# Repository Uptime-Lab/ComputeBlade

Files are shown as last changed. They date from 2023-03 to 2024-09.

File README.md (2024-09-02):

# This page is no longer being updated and the new repo is [uptime-industries/compute-blade](https://github.com/uptime-industries/compute-blade)

# Compute Blade Repository

- [Official website computeblade.com](https://computeblade.com/)

- [Official website uplab.pro](https://uplab.pro/)

- [Instagram](https://www.instagram.com/uptime.lab/)

- [Twitter](https://twitter.com/merocle)

- [Discord community](https://discord.com/servers/uptime-lab-952334175501946902)

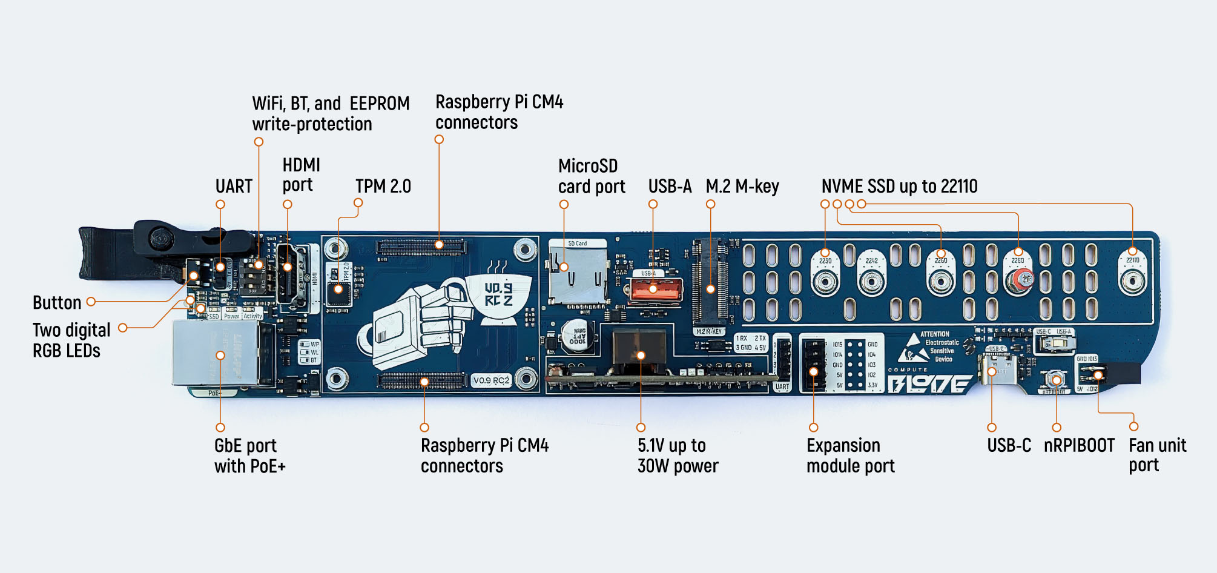
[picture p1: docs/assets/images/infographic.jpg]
Compute Blade


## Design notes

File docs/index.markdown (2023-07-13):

---
title: Compute Blade
layout: page
permalink: "/"
nav_order: 0
---

# Compute Blade

The device is a rack-mountable, PoE-powered carrier board for Raspberry Pi Compute Module 4 and compatible devices with all the necessary interfaces.
With Compute Blade, you can create a high-density, low-power-consuming, plug-and-play blade server for home or data-center use.

infographic

---

40 Raspberry Pi CM4 with NVMe drives in 2 server units:
* 160 ARM cores
* 320 GB Ram
* 20 TB Storage

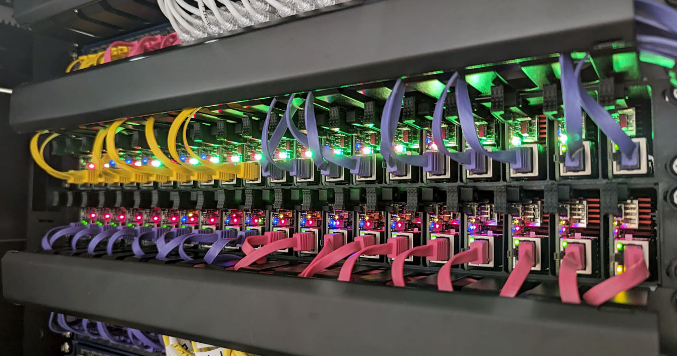
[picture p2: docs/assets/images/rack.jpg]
rack


---

There are 3 options
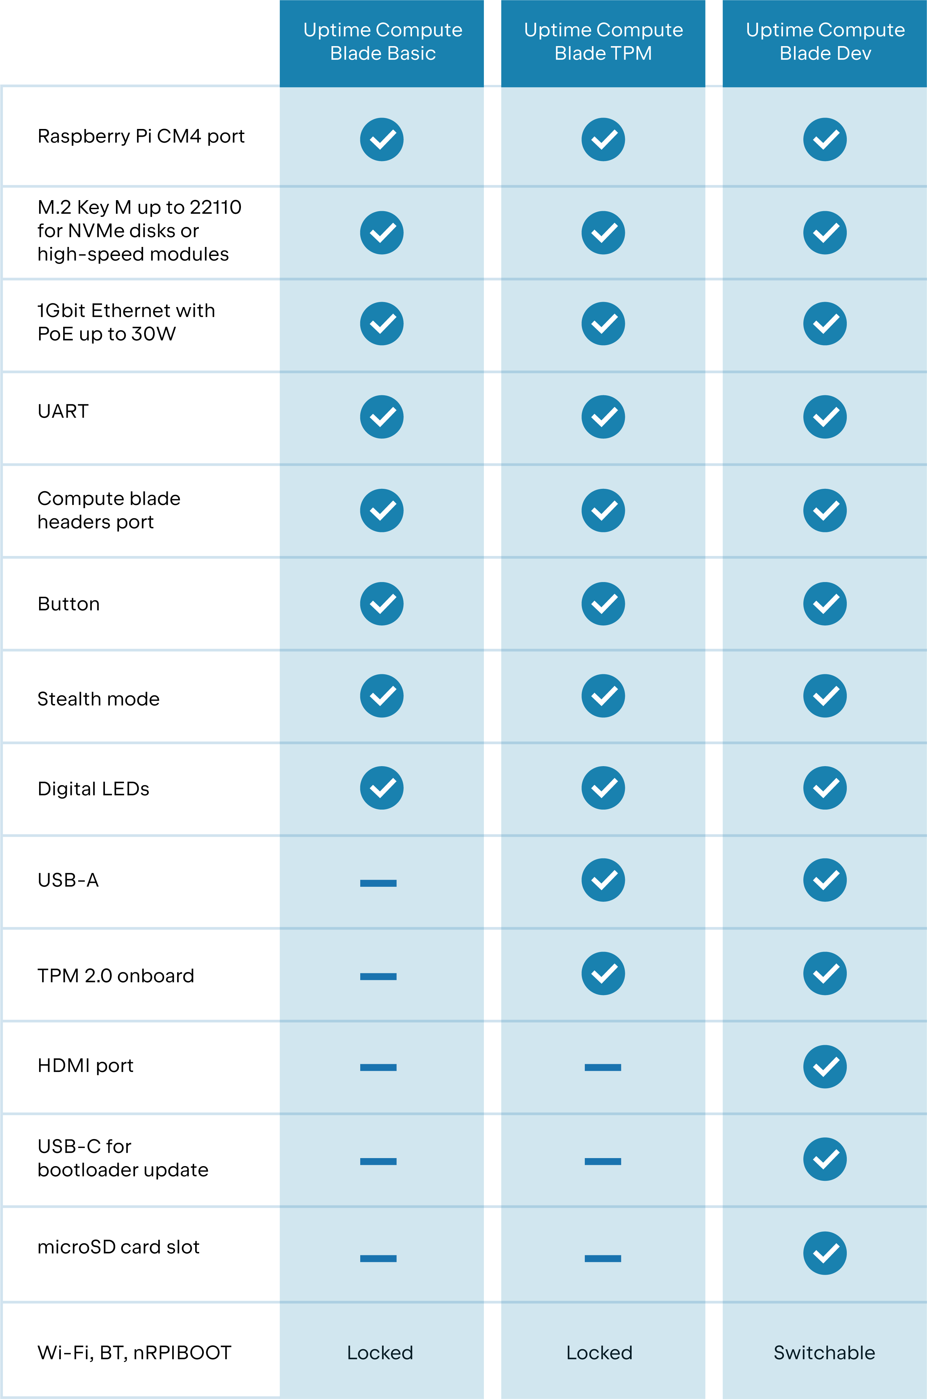
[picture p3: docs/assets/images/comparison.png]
comparison


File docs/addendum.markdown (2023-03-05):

---
title: Addendum
layout: page
permalink: "/addendum/"
nav_order: 7
---
## What do you need to pay attention

---

* The current iteration of the 3D-printed enclosure has a weakness.
I broke one of the Fan Unit latches by inattention, but in general you just need to not over bend or put the chassis standing on it on the table.

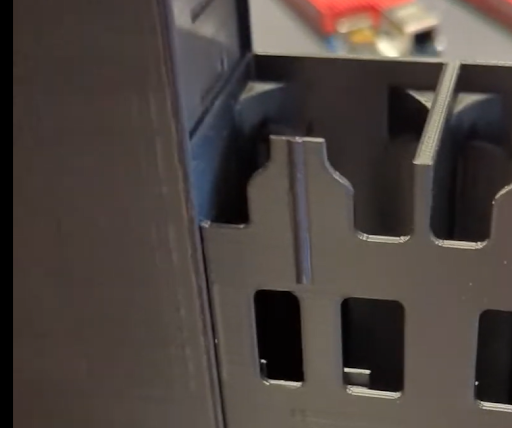
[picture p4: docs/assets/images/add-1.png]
add-1


---

* The second thing to look at is the contact of the Fan Unit assembly.\
  This may not be the most reliable option, because if the connector or pins are slightly bent, they will not fit together or may break. But this is the cheapest and easiest to replace option.
  Just make sure the first time that they are flat and fit together. You can start with a fanless assembly to check the case

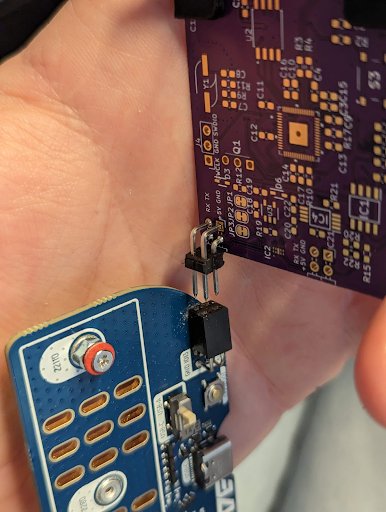
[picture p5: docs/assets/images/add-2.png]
add-2

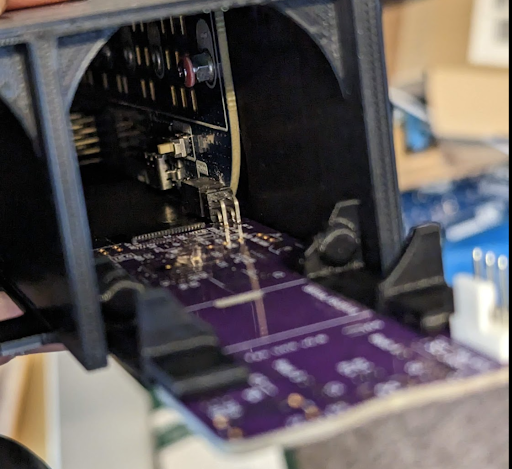
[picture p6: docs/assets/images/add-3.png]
add-3


---

* Processing traces on the edges of the **Compute Blade RC2** PCB\
  Some RC2 blades have irregularities on the borders of the circuit board (the places of separation of the plates), this will be corrected in version 1, but in the meantime need to finalize it with knife or any other tool (incidentally on some blades, I have already done it)

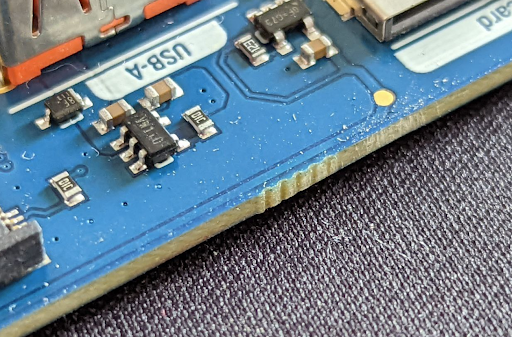
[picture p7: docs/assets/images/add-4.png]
add-4


---

* If you printed the case yourself, note that the blade should go in without difficulty. The model should be printed 1in1 with minimal error.
  When printing with the Cura slicer, I use a “horizontal expansion” setting of “-0.08”
  This is the challenge for the 3D printer. Best of luck!

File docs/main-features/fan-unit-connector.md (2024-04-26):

---
title: Square connector
layout: page
parent: Main Features (Basic Blade)
permalink: "/main-features/fan-unit-connector/"
---
## Square connector at the rear of the Blade

The square connector at the end of the Blade main purpose is to connect a Fan Unit.
The output is 5V and should work with any fan that supports 5V. The speed of the fan can be controlled with PWM.

But it can be used to control any 5v PWM fan. Or as an additional UART port (UART5 on CM4)

{: .warning }
Take care when wiring into this connector!

### UART connection (Smart Fan Unit)

On the Blade
Add to Config.txt

```bash
dtoverlay=uart5
```

> Note:
>
> to find out which port UART5 is on:
> ```bash
> /dev/tty*
> ```
> it would look something like this:
> ```bash
> /dev/ttyAMA1 or /dev/ttyAMA5
> ```

Console (use your UART port):

```bash
sudo apt-get install cu
sudo chmod 666 /dev/ttyAMA5
sudo cu -l /dev/ttyAMA5 -s 115200
```

Fan Unit code:

[https://github.com/merocle/FanUnit](https://github.com/merocle/FanUnit){:target="_blank"}

{: .highlight-title }

> Notes:
>
> to close **cu** session:
> ```bash
> ~.
> ```
> to check if session in the background (in case “**cu: /dev/ttyAMA1: Line in use**” error):
> ```bash
> jobs -l
> ```
> to return to current opened session:
> ```bash
> fg
> ```

### PWM fan (non-smart Fan Unit)

When using a dumb Fan Unit the fan is controlled from the left blade in the pair

Examples:

```bash
wget https://raw.githubusercontent.com/DriftKingTW/Raspberry-Pi-PWM-Fan-Control/master/read_fan_speed.py
```

{: .important }
>You need to change in the script:
>**TACH = 13**

Run the script:

```bash
python read_fan_speed.py
```

Fan Control example:
```bash
wget https://raw.githubusercontent.com/DriftKingTW/Raspberry-Pi-PWM-Fan-Control/master/fan_control.py
python fan_control.py
```

{: .important }
>You need to change in the script:
>**FAN_PIN = 12**

to run the script in the background quickly, run
```bash
nohup python fan_control.py
```
Links:
[https://blog.driftking.tw/](https://blog.driftking.tw/en/2019/11/Using-Raspberry-Pi-to-Control-a-PWM-Fan-and-Monitor-its-Speed/){:target="_blank"}

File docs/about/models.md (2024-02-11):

---
title: 3D Models
layout: page
parent: About
permalink: "/about/models/"
nav_order: 2
redirect_from:
- /models/
---

## Compute Blade
* [Compute Blade v1 DEV (.step)](/assets/files/Compute_Blade_v1_DEV.step){:target="_blank"}
* [Compute Blade v1 TPM (.step)](/assets/files/Compute_Blade_v1_TPM.step){:target="_blank"}
* [Compute Blade v1 Basic (.step)](/assets/files/Compute_Blade_v1_Basic.step){:target="_blank"}

Outdated:
* [Compute Blade RC2 DEV (.step)](/assets/files/Compute_Blade_RC2_DEV.step){:target="_blank"}

## Fan Unit
* [Smart Fan Unit (.step)](/assets/files/Fan_Unit_Smart_V1.1.step){:target="_blank"}
* [Non-smart Fan Unit (.step)](/assets/files/Fan_Unit_Dumb_V1.1.step){:target="_blank"}

## BladeRunner enclosure

* Models for 3D printing are available in [the official repository of the enclosure (link)](https://github.com/Uptime-Lab/BladeRunner){:target="_blank"} 

{: .note-title }
> License
>
> Creative Commons Attribution-ShareAlike (CC BY-SA)

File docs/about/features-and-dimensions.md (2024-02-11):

---
title: Features and Dimensions
layout: page
parent: About
permalink: "/about/features-and-dimensions/"
nav_order: 1
---

<details open markdown="block">
  <summary>
    Table of contents
  </summary>
  {: .text-delta }
- TOC
{:toc}
</details>

## Compute Blade

infographic

### List of Dev revision features

* Raspberry Pi CM4 support
* NVMe SSD up to 22110 (2230, 2242, 2260, 2280 supported)
* Gigabit Ethernet
* Power over Ethernet IEEE 802.3at (PoE+) up to 25.5W (30W peak)
* Raspberry Pi CM4 by PoE 5.1V power supply, which has improved stability under overclocking.
* USB-A for a flash drive for copying data during setup with UART or YubiKey keys during operation.
* MicroSD card port
* UART0 on the front (TX, RX, GND)
* Additional UART0 with 5v in (or out) next to module port
* Two digital RGB LEDs
* Hardware switchable WiFi, BT, and EEPROM write-protection
* Activity, Power, and SSD LEDs
* HDMI port for connecting a monitor (up to 4k60)
* USB-C port and PRIBOOT button to flash the bootloader, access to eMMC/SD card, or tests.
* TPM 2.0 onboard
* PWM fan connector for the custom backplane (Fan Units), supports UART communication.
* Switchable USB input (USB-A or USB-C)
* Programmable button on the front panel
* IEEE 802.3at detection (on Raspberry Pi with GPIO pin and additional LED on the blade).
* Toggleable front LEDs that can be turned off

[Version comparison table](/#comparison)

### Blade Dimensions

* 42,5mm x 255mm x 17.5mm
<br />or
* 1,67" x 10" x 0,69"

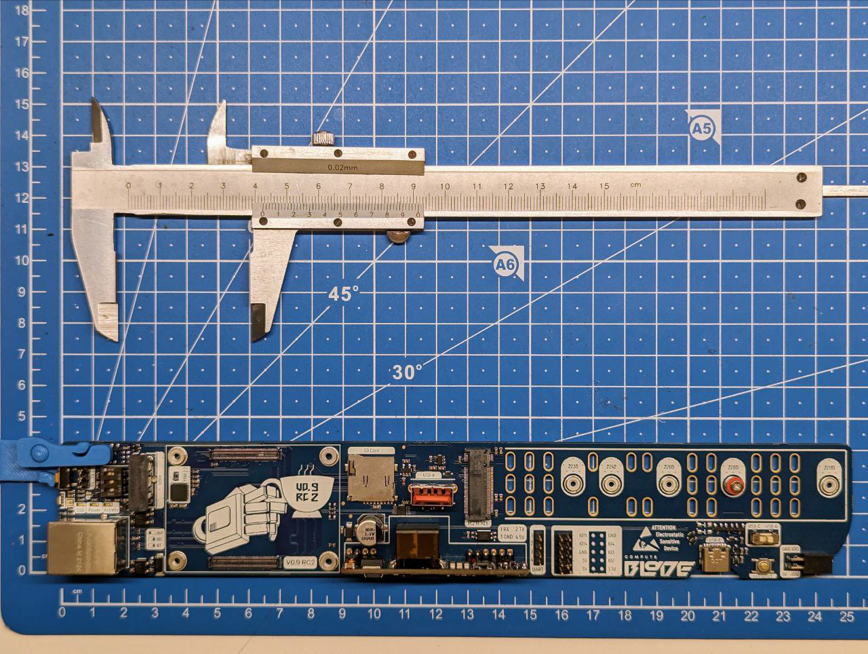
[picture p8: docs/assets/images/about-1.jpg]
Dimensions-1

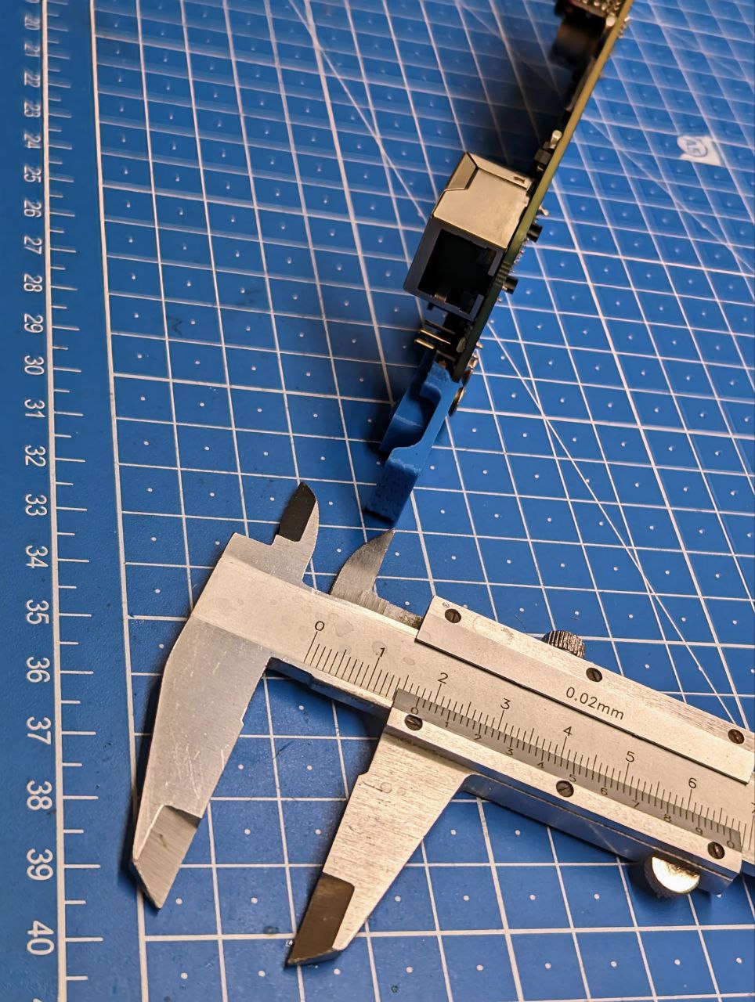
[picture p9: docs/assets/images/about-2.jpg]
Dimensions-2


### Compute Blade Changelog

[From concept to RC2 on uplab.pro](https://uplab.pro/2022/03/compute-blade-changelog/){:target="_blank"}

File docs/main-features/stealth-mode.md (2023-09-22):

---
title: Stealth mode
layout: page
parent: Main Features (Basic Blade)
permalink: "/main-features/stealth-mode/"
---

## Stealth mode

Stealth mode will turn off all but the Digital LEDs at once. It is implemented via a GPIO and a transistor, which means it won't harm the Blade functionality. It is possible to change the brightness using software PWM however in some cases, it may not work perfectly.

Compute Blade RC2 cannot turn off the LEDs on the Ethernet port this way, but they can be turned off in other ways. The Digital LEDs will also not be turned off due to technical limitations, but since they are controlled from the GPIO this should not be a problem.\

Initialization in the terminal:

```bash
echo "21" > /sys/class/gpio/export
echo "out" > /sys/class/gpio/gpio21/direction
```

To turn off the LEDs:

```bash
echo "1" > /sys/class/gpio/gpio21/value
```

To turn on the LEDs:

```bash
echo "0" > /sys/class/gpio/gpio21/value
```

To do this immediately after booting the OS, you can add these commands to /etc/rc.local:

```bash
sudo nano /etc/rc.local
```

```bash
#!/bin/sh -e
#
# rc.local
#

echo "21" > /sys/class/gpio/export
sleep 0.1
echo "out" > /sys/class/gpio/gpio21/direction
echo "1" > /sys/class/gpio/gpio21/value
sleep 0.1

exit 0
```

To switch off LEDs on the Ethernet port add these lines to /boot/config.txt ([Source](https://github.com/raspberrypi/linux/blob/rpi-5.15.y/arch/arm/boot/dts/overlays/README#L172){:target="_blank"})

```bash
#disable ethernet port LEDs
dtparam=eth_led0=14
dtparam=eth_led1=14
```

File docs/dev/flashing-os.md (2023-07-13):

---
title: Flashing OS to eMMC / accessing eMMC
layout: page
parent: Compute Blade Dev
permalink: "/dev/flashing-os/"
---
### Flashing OS to eMMC / accessing eMMC

In short, it's like this:

- On a computer with Linux to which you will connect the Blade

```bash
sudo apt install libusb-1.0-0-dev
git clone --depth=1 https://github.com/raspberrypi/usbboot
cd usbboot
make
cd recovery
sudo ./rpiboot
```

If you have a Mac OS you need [Homebrew](https://brew.sh/){:target="_blank"}

```bash
brew install pkgconfig libusb
```
- Slide the USB switch to USB-C. Press Boot (nRPIBOOT) on the Blade and connect it to your Linux/Mac with USB-C cable

- After that you will be able to mount the Boot partition if present. (it usually happens automatically). Note a stock CM4 has a completely empty eMMC.

You can fix your files/configs or install the OS using the [Raspberry Pi Imager](https://www.raspberrypi.com/software/){:target="_blank"}

For complete instructions, see Jeff Geerling's website: [instructions](https://www.jeffgeerling.com/blog/2020/how-flash-raspberry-pi-os-compute-module-4-emmc-usbboot){:target="_blank"}

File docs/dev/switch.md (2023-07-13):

---
title: Write Protection, Wireless, and Bluetooth Switch
layout: page
parent: Compute Blade Dev
permalink: "/dev/switch/"
---

### Write Protection, Wireless, and Bluetooth Switch

You are able to turn off wireless, Bluetooth and enable the bootloader write protection  
The following pins are:

1 - Write Protection (left - disabled)

2 - Wi-Fi (left - enabled)

3 - Bluetooth (left - enabled)

Switch only when the Blade is off

To activate write protection, you also need to flash the bootloader. Just follow the steps in the official documentation. [Link](https://www.raspberrypi.com/documentation/computers/compute-module.html#cm4bootloader){:target="_blank"}

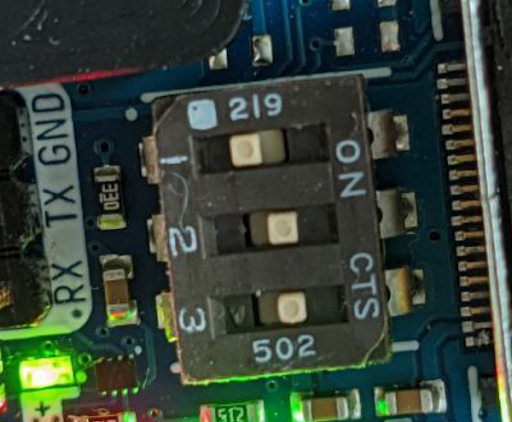
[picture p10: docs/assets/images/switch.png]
switch


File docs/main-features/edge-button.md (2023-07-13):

---
title: Edge button
layout: page
parent: Main Features (Basic Blade)
permalink: "/main-features/edge-button/"
---

## Edge button

{: .note }
The button is connected to GPIO20 in the Raspberry PI compute module and can be customized as you like.
Can be pressed with a left touch of the Blade latch.

Python script example:

```python
import RPi.GPIO as GPIO
import time

GPIO.setmode(GPIO.BCM)
GPIO.setup(20, GPIO.IN, pull_up_down=GPIO.PUD_UP) #Button to GPIO20

try:
    while True:
         button_state = GPIO.input(20)
         if button_state == False:
             print('Button Pressed...')
             time.sleep(0.2)
except:
    GPIO.cleanup()
```

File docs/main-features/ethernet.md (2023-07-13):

---
title: Ethernet with PoE
layout: page
parent: Main Features (Basic Blade)
permalink: "/main-features/ethernet/"
nav_order: 3
---

# Ethernet with PoE

The Compute Blade features a Gigabit Ethernet port that supports IEEE 802.3at (PoE+) and 802.3af (PoE).

## Power Consumption

Power consumption will vary based on load, accessories connected, the power requirements of any devices installed in the M.2 slot, whether or not the CM4 is overlocked, etc.

A compute blade with a CM4 overlocked to 2GHz and a normal NVMe SSD consumes ~7W under load. Normal operation may range from 3W to 17W.

A cluster of 40 blades running CI/CD tasks in a production environment consumes 260-280W, with 20 blades @ 1.8GHz and 20 blades overclocked to 2GHz.

## Cost

The cost to run a blade will depend on the power consumption considerations noted above and your local utility provider's rates. Some providers will vary the cost of electricity over the course of a day (peak vs. non-peak), which can further complicate the equation.

You can use an [energy cost calculator](https://www.rapidtables.com/calc/electric/energy-cost-calculator.html){:target="_blank"} to figure out kWh per day, month, or year, then mulitply that by your local utility provider's rates to determine the total cost to run a blade.

Examples: 

If a blade consumes 10W and runs 24 hours a day, that's 0.24 kWh/d. A fully-populated 19" rack mount shelf with 20 blades would consume 4.8 kWh/d.

* USD: At $0.20 per kWh, a blade would cost $0.048/d, or $0.96/d for a full shelf.
* EUR: At €0.19 per kWh, a blade would cost €0.046/d, or €0.82/d for a full shelf.

## PoE Modules

Different Compute Blade revisions use different PoE modules. See the table below.

| Version | PoE Module | Volts | Watts (Peak) | PoE Support | Classification |
|:---|:---|:---|:---|:---|:---|
| RC2 | [Silvertel Ag5305](https://silvertel.com/ag5300/){:target="_blank"} | 5V | 20W (22W) | IEEE 802.3af, 802.3at | Type 2, Class 4 <sup>1</sup> |
| v1.0 | [Silvertel Ag5405](https://silvertel.com/ag5400/){:target="_blank"} | 5V | 25.5W (30W)  | IEEE 802.3af, 802.3at, 802.3bt | Type 2, Class 4 <sup>2</sup> |

<sup>1</sup> _"The Ag5300 classification is fixed at Class 4, this means that an IEEE802.3at Type 1 or an IEEE802.3af PSE will default to Class 0. However an IEEE802.3at or IEEE802.3bt PSE will recognise the Class 4 as a Type 2 PD." ([source](https://silvertel.com/images/datasheets/Ag5300-datasheet-smallest-30W-Power-Over-Ethernet-Plus-Module-PoEplusPD.pdf))_

<sup>2</sup> _"The Ag5400 is a fixed Type 2 - Class 4 PD requesting 30W of power from a compliant IEEE802.3 Type 2 or greater PSE by displaying the correct class pulses shown in Table 3 below. If the Ag5400 is connected to a Type 1 PSE, the PSE will not recognise the Class 4 request from the Ag5400 and default to a Class 3 power level device and supply 15.4W." ([source](https://silvertel.com/images/datasheets/Ag5400-datasheet-high%20Efficiency-30W-Power-Over-Ethernet-Plus-Module-PoE+PD.pdf))_

## PoE Standards

This is not meant to be an exhaustive reference. For detailed information, see [Power over Ethernet](https://en.wikipedia.org/wiki/Power_over_Ethernet){:target="_blank"}.

| Standard | Common Name  | Type | PD | Max. PSE | 
|:---|:---|:-----|:---|:---|
| [IEEE 802.3af](https://standards.ieee.org/ieee/802.3af/1090/){:target="_blank"} | PoE | 1 | 12.95W | 15.4W |
| [IEEE 802.3at](https://standards.ieee.org/standard/802_3at-2009.html){:target="_blank"} | PoE+ | 2 | 25.5W  | 30.0W |
| [IEEE 802.3bt](https://standards.ieee.org/ieee/802.3bt/6749/){:target="_blank"} | PoE++, 4PPoE | 3 | 51W | 60W |
| [IEEE 802.3bt](https://standards.ieee.org/ieee/802.3bt/6749/){:target="_blank"} | PoE++, 4PPoE | 4 | 71.3W  | 100W |

Use Cat5 cabling or better. Cat3 can be used in certain low-power situations, but most should not find themselves in a situation where Cat3 is needed.

## Switch Recommendation

A switch that supports IEEE 802.3at (PoE+) is recommended. However, IEEE 802.3af (PoE) is sufficient for a blade with a CM4 @ 1.8GHz and a standard NVMe SSD. Future M.2 modules (Coral, RAID, etc.) will require more power; 802.3af may not be adequate.

### Considerations

* PoE standard(s) supported.
* PoE budget.<sup>1</sup>
* Port count.
* Port speed.
* Form factor.

<sup>1</sup> _Note the switch's PSU, switch power consumption, and power available to PoE. Switches are not always capable of providing full power to all available switch ports. For example, a switch with a 500W PSU, with 50W switch power consumption, has a 450W PoE budget. That allows 26.25W per port for a 24-port switch, but only 9.375W for a 48-port switch._ 

### Switches In Use

A list of switches that Compute Blade users have successfully used to connect and power Compute Blades. For reference only.

| Switch | Part No. | Ports | PoE |
|:---|:---|:---|:---|
| [Aruba CX6100 12G](https://www.arubanetworks.com/de/products/switches/access/6100-series/){:target="_blank"} | JL679A | 14x 1GbE RJ45, 2x 1/10GbE SFP+ | 12x PoE+ |
| [Ubiquiti Switch Pro 24 PoE](https://store.ui.com/products/usw-pro-24-poe){:target="_blank"} | USW-PRO-24-POE | 24x 1GbE RJ45, 2x 1/10GbE SFP+ | 16x PoE+, 8x PoE++ |
| [HP 5120-48G-POE+](https://support.hpe.com/hpesc/public/docDisplay?docId=emr_na-c00778577){:target="_blank"} | JG237A | 48x 1GbE RJ45, 4x SFP, 2x Expansion | 48x PoE+ |
| [Juniper EX3300-24P](https://www.juniper.net/documentation/en_US/release-independent/junos/information-products/pathway-pages/ex-series/ex3300/ex3300.pdf){:target="_blank"} | EX3300-24P | 24x 1GbE RJ45, 4x 1/10GbE SFP+ | 24x PoE+ |
| [Juniper EX3300-48P](https://www.juniper.net/documentation/en_US/release-independent/junos/information-products/pathway-pages/ex-series/ex3300/ex3300.pdf){:target="_blank"} | EX3300-48P | 48x 1GbE RJ45, 4x 1/10GbE SFP+ | 48x PoE+ |
| [Zyxel GS1200-5HP v2](https://www.zyxel.com/us/en-us/products/switch/5-port-8-port-web-managed-poe-gigabit-switch-gs1200-poe-series){:target="_blank"} | GS1200-5HPV2-EU0101F | 5x 1GbE RJ45 | 4x PoE+ |

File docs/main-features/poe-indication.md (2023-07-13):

---
title: PoE+ indication
layout: page
parent: Main Features (Basic Blade)
permalink: "/main-features/poe-indication/"
nav_order: 4
---

# PoE+ Indicator

The PoE+ Indicator can be used to monitor power supply failures or limit RaspberryPi overclocking, when power is provided via 802.3af only.
There is an LED on the Blade with a `+` label indicating the PoE+ power state.
Alongside, GPIO23 can be used to identify the power state.

|--------------------|--------------------------------------------|----------|----------------|
| LED Color          | Description                                | GPIO 23  | Power          |
|--------------------|--------------------------------------------|----------|----------------|
| Red                | 5 Volt present (PoE or USB-C or 5v direct) | **HIGH** | 12W            |
| Orange (Red+Green) | PoE+ (802.3at) present                     | **LOW**  | 25W (RC2: 22W) |
|--------------------|--------------------------------------------|----------|----------------|

<table>
  <tr>
    <td>
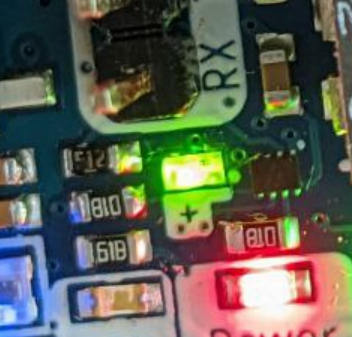
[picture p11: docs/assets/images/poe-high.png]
        
        <h3>PoE or USB-C or 5v direct </h3>
    </td>
    <td>
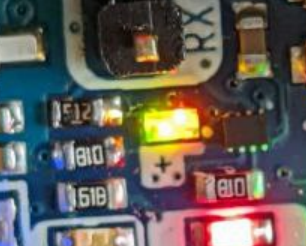
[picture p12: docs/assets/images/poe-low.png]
        
        <h3>PoE+ Detected </h3>
    </td>
   </tr>
</table>

## Accessing the PoE+ status in software

The GPIO23 indicates the PoE+ state, this Python script can e.g. used to detect the status.

```python
import RPi.GPIO as GPIO
import time

POE_INDICATOR_GPIO = 23

GPIO.setmode(GPIO.BCM)
GPIO.setup(POE_INDICATOR_GPIO, GPIO.IN, pull_up_down=GPIO.PUD_UP) # PoE indicator

try:
     button_state = GPIO.input(POE_INDICATOR_GPIO)
     if button_state == False:
        print("Powersource: 802.3at")
    else:
        print("Powersource: 802.3af or USB-C")
except:
    GPIO.cleanup()
```

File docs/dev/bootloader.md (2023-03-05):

---
title: Flashing the bootloader
layout: page
parent: Compute Blade Dev
permalink: "/dev/bootloader/"
---
### Flashing the bootloader

To flash the bootloader, you need to turn on the Blade with the nRPIBOOT button pressed (a second after turning the Blade on, you can already release it).
You can turn it on from USB-C or PoE; it doesn't matter. To flash, you need to plug in a USB-C and switch the switch to USB-C (the switch can be switched during operation).

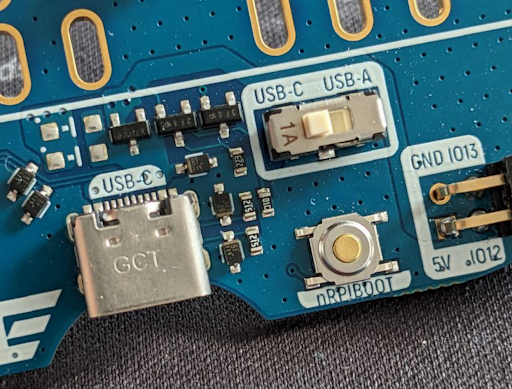
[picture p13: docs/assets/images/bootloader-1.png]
bootloader-1


On a computer with Linux to which you will connect the Blade:

```bash
sudo apt install libusb-1.0-0-dev
git clone --depth=1 https://github.com/raspberrypi/usbboot
cd usbboot
make
cd recovery
nano boot.conf
```

change the line

```
BOOT_ORDER=0xf16
```

That means:

Try NVMe first, followed by SD then repeat.

You can find more about boot order by following this [link](https://www.raspberrypi.com/documentation/computers/raspberry-pi.html#BOOT_ORDER){:target="_blank"}.

Optionally, I also recommend correcting 0 to 1 on this line to enable UART on boot

```
BOOT_UART=1
```

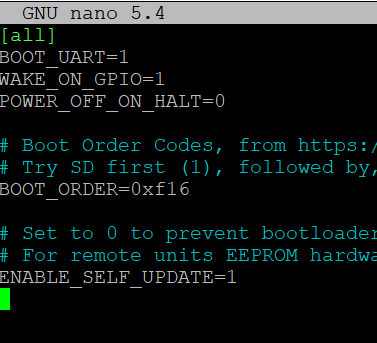
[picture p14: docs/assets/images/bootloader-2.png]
bootloader-2


To update to the latest bootloader version use [repo](https://github.com/raspberrypi/rpi-eeprom/tree/master/firmware){:target="_blank"} and the right link:

```bash
rm -f pieeprom.original.bin
curl -L -o pieeprom.original.bin  https://github.com/raspberrypi/rpi-eeprom/raw/master/firmware/stable/pieeprom-2022-12-07.bin
```

```bash
./update-pieeprom.sh
cd ../
sudo ./rpiboot -d recovery
```

If UART is connected, you will see the firmware status. If the HDMI port is connected, the screen will turn green.

on UART (you should use BOOT_UART=1 in boot.conf):

bootloader-3

Check the bootloader version:

```bash
vcgencmd bootloader_version
```

Also, on the UART when booting:

bootloader-4

If the screen is red and in the UART during flashing:

```
Bad signature pieeprom.bin
FATAL error-code 24
```

You are probably using the wrong pieeprom.original.bin image. The right one should be 512k in size.

pieeprom.original.bin

In my case, the problem was due to an incorrect link (**blob** in the path):

~~https://github.com/raspberrypi/rpi-eeprom/blob/master/firmware/stable/pieeprom-2022-09-02.bin~~The correct one:

https://github.com/raspberrypi/rpi-eeprom/raw/master/firmware/stable/pieeprom-2022-09-02.bin

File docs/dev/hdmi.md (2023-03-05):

---
title: HDMI
layout: page
parent: Compute Blade Dev
permalink: "/dev/hdmi/"
---

### HDMI

The HDMI port is mostly designed for debugging. The port is fragile, so be careful. If possible, use a small flexible cable. If it does break off take care to ensure the board isn’t shorted.

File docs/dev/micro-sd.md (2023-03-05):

---
title: MicroSD card slot
layout: page
parent: Compute Blade Dev
permalink: "/dev/micro-sd/"
---

### MicroSD card slot

The MicroSD card slot only works with the Raspberry Pi CM4 lite

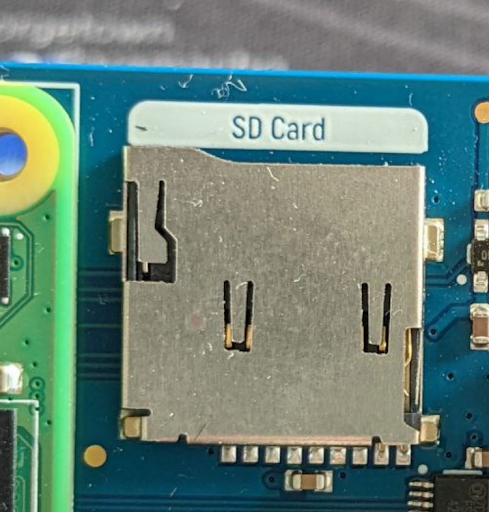
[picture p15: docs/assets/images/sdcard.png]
sdcard


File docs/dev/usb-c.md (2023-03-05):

---
title: USB-C
layout: page
parent: Compute Blade Dev
permalink: "/dev/usb-c/"
---

### USB-C

The compute module can only operate one USB port at a time. 
There is a switch to enable which port you would like to utilize.

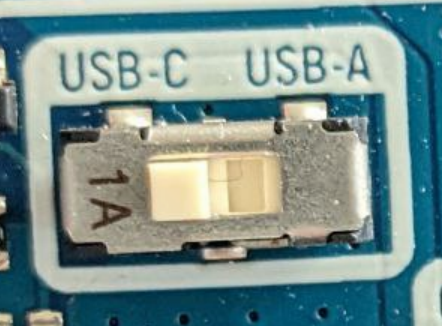
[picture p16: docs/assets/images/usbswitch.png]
usbswitch


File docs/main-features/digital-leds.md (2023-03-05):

---
title: Digital LEDs
layout: page
parent: Main Features (Basic Blade)
permalink: "/main-features/digital-leds/"
---
## Digital LEDs

The blade has two digital LEDs mounted in series. A square yellow LED is located on the top of the board, and a green LED is located on edge.

{: .note }
Both LEDS are connected in series to GPIO18 on the compute module.

Preparation:

You'll need to install the Adafruit_Blinka library that provides CircuitPython support in Python:

[https://learn.adafruit.com/circuitpython-on-raspberrypi-linux/installing-circuitpython-on-raspberry-pi](https://learn.adafruit.com/circuitpython-on-raspberrypi-linux/installing-circuitpython-on-raspberry-pi){:target="_blank"}

And then NeoPixel Library:

[https://learn.adafruit.com/neopixels-on-raspberry-pi/python-usage](https://learn.adafruit.com/neopixels-on-raspberry-pi/python-usage){:target="_blank"}

{: .note }

Newer CM4 Revisions aren’t included in rpi-ws281x yet (e.g. Compute Module 4 Rev 1.1). If you get **“RuntimeError: ws2811_init failed with code -3 (Hardware revision is not supported)”**, you need to follow [these steps](https://github.com/rpi-ws281x/rpi-ws281x-python/issues/56#issuecomment-753320723){:target="_blank"}

Here is an example Python script that will show you the CPU temperature on the square LED and the CPU load on edge LED. And use the button for blade identification. And [demo](https://twitter.com/Merocle/status/1569364547143897088?s=20&t=DmDRg0925cGQrCRTUISCFg){:target="_blank"}

```python
from time import sleep
import board
import neopixel
import psutil
import RPi.GPIO as GPIO

g,r,b = 0,0,0
mintemp = 40 #Temperature Boundaries. Closer to this is green
maxtemp = 70 #Temperature Boundaries. Closer to this is red
LEDbrightness = 0.2 #Yes, you can change the brightness here
Button = 20
flag = 0

GPIO.setwarnings(False)
GPIO.setmode(GPIO.BCM)
GPIO.setup(Button,GPIO.IN,pull_up_down=GPIO.PUD_UP)
pixels = neopixel.NeoPixel(
    board.D18, 2, brightness=LEDbrightness, auto_write=False, pixel_order=neopixel.GRB
)

def show(percent, pixel):
    a = int(round((510 / 100) * percent))
    if a > 255:
        r = 255
        g = 510 - a
    else:
        r = a
        g = 255
    pixels[pixel] = (g, r, b)
    pixels.show()
#    return print('showed', a, 'on', pixel)

while True:
    temp = int(round(psutil.sensors_temperatures()["cpu_thermal"][0].current))
#    print('temp = ', temp)
    button_state = GPIO.input(Button)
    if mintemp <= temp <= maxtemp:
        temp = temp - mintemp
        mtemp = maxtemp - mintemp
        c = int(round((temp / mtemp) * 100))
        show(c, 0)
    elif temp < mintemp:
        pixels[0] = (255, 0, 0)
    else:
        pixels[0] = (0, 255, 0)

    sleep(0.1)

    load = psutil.cpu_percent()
 #   print('load = ', load)
    show(load, 1)
    sleep(0.1)

    if button_state == 0:
        sleep(0.5)
        if flag == 0:
            flag = 1
        else:
            flag = 0
    if flag == 1:
        print('Blade ID is active')
        pixels[1] = (0, 0, 255)

    else:
        print('Blade ID isn\'t active')
```

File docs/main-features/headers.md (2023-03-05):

---
title: Compute blade headers
layout: page
parent: Main Features (Basic Blade)
permalink: "/main-features/headers/"
nav_order: 6
has_children: true
---

You can use Real-Time Clocks (RTCs) for the Raspberry Pi and other compatible modules.
<br />
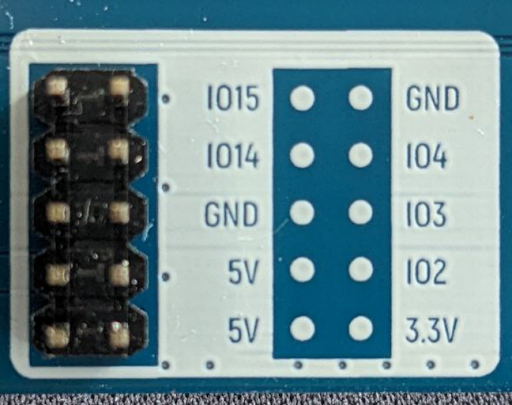
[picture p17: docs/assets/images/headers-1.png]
headers-1


This is the top part of the standard GPIO connector of the Raspberry Pi (upside down)

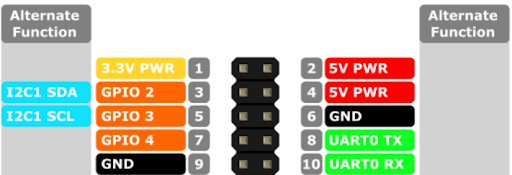
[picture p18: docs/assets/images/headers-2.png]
headers-2
<br />
 [picture source](https://learn.microsoft.com/de-de/windows/iot-core/learn-about-hardware/pinmappings/pinmappingsrpi){:target="_blank"}
{: .fs-1 }
<br />

{: .note }
This section of the documentation will be updated

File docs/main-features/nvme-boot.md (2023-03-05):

---
title: NVMe Boot
layout: page
parent: Main Features (Basic Blade)
permalink: "/main-features/nvme-boot/"
nav_order: 1
---

Works out of the box on the latest (after July 2021) Raspberry Pi CM4. 
If you're not using the latest Raspberry Pi CM4, you’ll need to [update the bootloader](/dev/bootloader/) specifying the correct boot order.

Use standoff for the NVMe drive, 2mm (2.5mm works fine) high.\
**M.2 key M** connection port. Sizes: 
* 2230
* 2242
* 2260
* 2280
* 22110

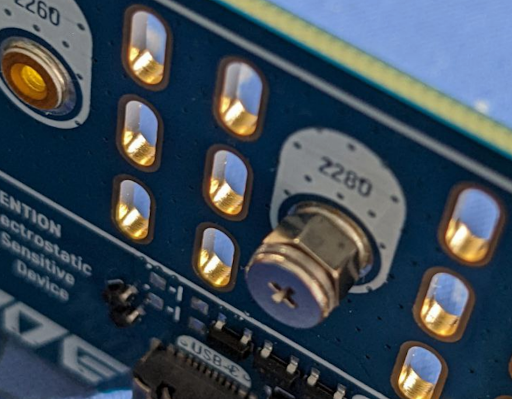
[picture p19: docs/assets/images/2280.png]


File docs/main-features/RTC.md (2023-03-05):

---
title: Real-Time Clocks
layout: page
parent: Compute blade headers
grand_parent: Main Features (Basic Blade)
permalink: "/main-features/headers/rtc/"
nav_order: 1
---
### Using and configuring the RTC module
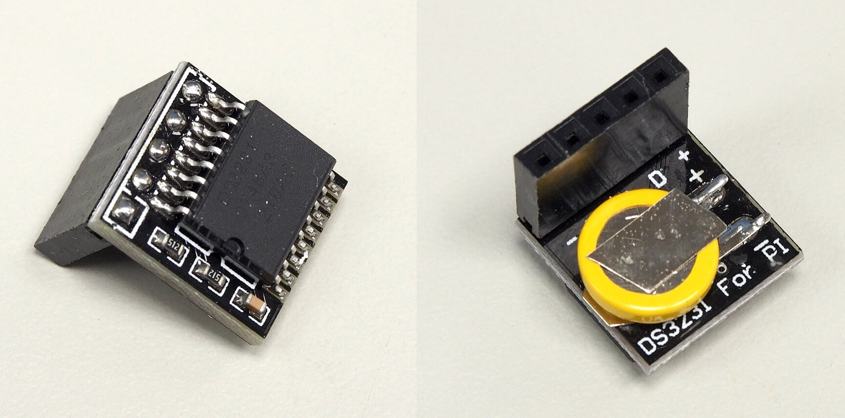
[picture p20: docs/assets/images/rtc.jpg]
rtc


In config:
```bash
dtoverlay=i2c-rtc,ds3231
dtparam=i2c_arm=on
```

Reboot and then check it in the terminal that the i2c device is available:

```bash
sudo i2cdetect -l|sort
sudo i2cdetect -y 1 
```

Next is the setup:

```bash
sudo apt-get -y remove fake-hwclock
sudo update-rc.d -f fake-hwclock remove
sudo systemctl disable fake-hwclock
```

Edit the file **hwclock-set**:

```bash
sudo nano /lib/udev/hwclock-set
```
Complete file:
```bash
#!/bin/sh
# Reset the System Clock to UTC if the hardware clock from which it
# was copied by the kernel was in localtime.

dev=$1

#if [ -e /run/systemd/system ] ; then
#    exit 0
#fi

if [ -e /run/udev/hwclock-set ]; then
    exit 0
fi

if [ -f /etc/default/rcS ] ; then
    . /etc/default/rcS
fi

# These defaults are user-overridable in /etc/default/hwclock
BADYEAR=no
HWCLOCKACCESS=yes
HWCLOCKPARS=
HCTOSYS_DEVICE=rtc0
if [ -f /etc/default/hwclock ] ; then
    . /etc/default/hwclock
fi

if [ yes = "$BADYEAR" ] ; then
#    /sbin/hwclock --rtc=$dev --systz --badyear
    /sbin/hwclock --rtc=$dev --hctosys --badyear
else
#    /sbin/hwclock --rtc=$dev --systz
    /sbin/hwclock --rtc=$dev --hctosys
fi

# Note 'touch' may not be available in initramfs
> /run/udev/hwclock-set
```

Reboot and check in terminal:

```bash
timedatectl status
```

Read:

```bash
sudo hwclock -r
```

Write:

```bash
sudo hwclock -w
```

Additional info

```bash
sudo hwclock --verbose
```

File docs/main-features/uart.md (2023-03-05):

---
title: UART
layout: page
parent: Main Features (Basic Blade)
permalink: "/main-features/uart/"
nav_order: 2
---
This is the same UART0 port, but with the big one, you can use 5V in/out (in "in" mode ONLY if the Blade has no other power source)

{: .note }
> Connect "correctly":
> * RX -> TX
> * TX -> RX
> * GND -> GND

in config:
```bash
enable_uart=1
```

You can [change the bootloader setting](/dev/bootloader/) to enable UART from the boot.
Add this line to boot.conf and flash the bootloader:
```bash
BOOT_UART=1
```
Follow [this link](https://www.raspberrypi.com/documentation/computers/raspberry-pi.html#BOOT_UART){:target="_blank"} to the Raspberry Pi Documentation BOOT_UART value

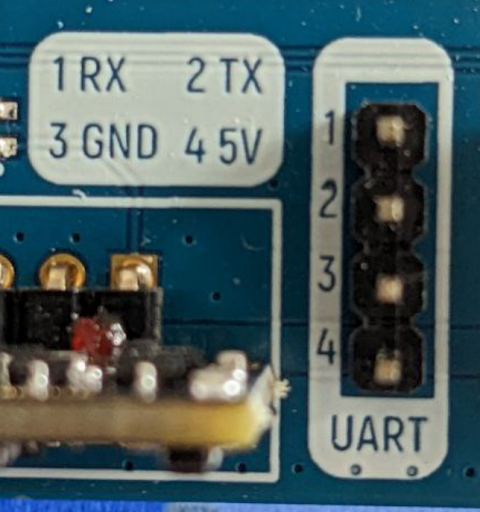
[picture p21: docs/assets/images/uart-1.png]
uart-1

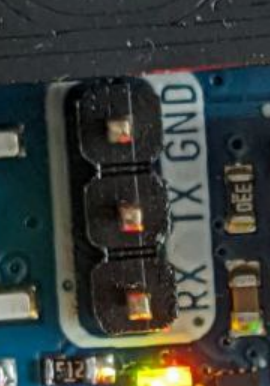
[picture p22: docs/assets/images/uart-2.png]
uart-2


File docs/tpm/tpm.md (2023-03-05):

---
title: TPM and Secure Boot
layout: page
parent: Compute Blade TPM and Dev
permalink: "/tpm-and-dev/tpm/"
---
## TPM

In config:

```bash
dtparam=spi=on dtoverlay=tpm-slb9670
```

To check

In terminal:

```bash
mkdir infineon-tpm 
git clone https://github.com/infineon/eltt2
cd eltt2
make
sudo ./eltt2 -g
cd ..
```

For more information, please see these links:
[https://www.infineon.com/dgdl/Infineon-OPTIGA-TPM-Quick-Start-Guide-AdditionalProductInformation-v03_00-EN.pdf](https://www.infineon.com/dgdl/Infineon-OPTIGA-TPM-Quick-Start-Guide-AdditionalProductInformation-v03_00-EN.pdf){:target="_blank"}

[https://aws.amazon.com/ru/blogs/iot/using-a-trusted-platform-module-for-endpoint-device-security-in-aws-iot-greengrass/](https://aws.amazon.com/ru/blogs/iot/using-a-trusted-platform-module-for-endpoint-device-security-in-aws-iot-greengrass/){:target="_blank"}

## Secure Boot

At the end of 2022, Secure Boot support appeared.

Secure boot is a mechanism for verifying the integrity of the kernel+initramfs and other files required during boot by storing them in a signed ramdisk image. These files include the GPU firmware (start.elf etc), kernel, initrd, Device Tree and overlays.

Secure Boot Quickstart:

[https://github.com/raspberrypi/...](https://github.com/raspberrypi/usbboot/blob/master/secure-boot-example/README.md){:target="_blank"}

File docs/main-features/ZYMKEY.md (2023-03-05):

---
title: ZYMKEY 4i
layout: page
parent: Compute blade headers
grand_parent: Main Features (Basic Blade)
permalink: "/main-features/headers/zymkey/"
nav_order: 2
---
### ZYMKEY 4i

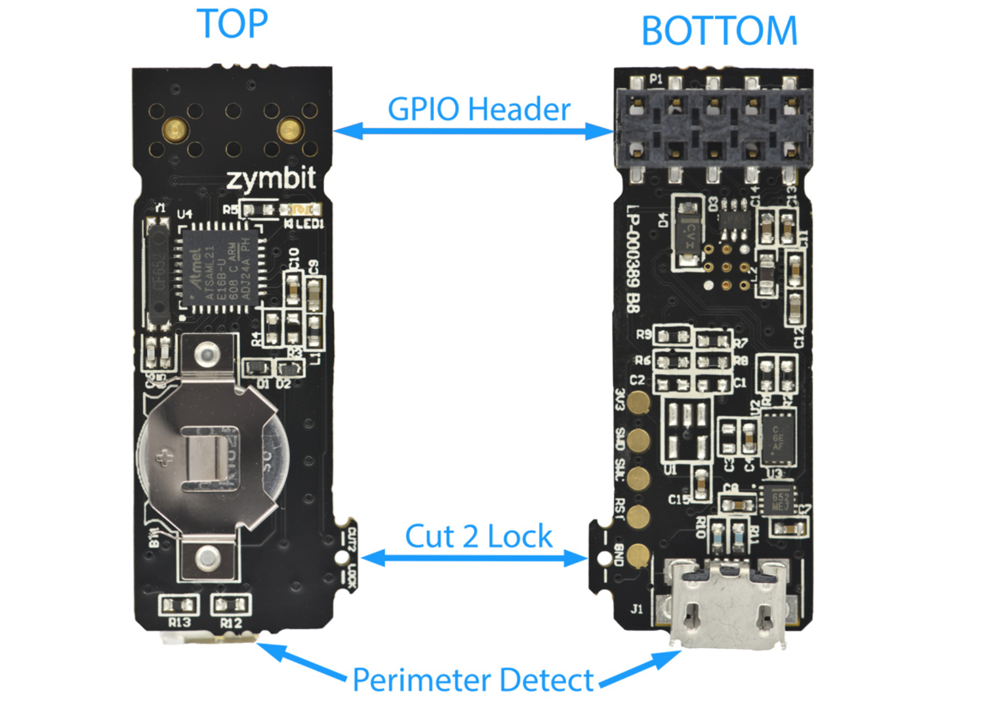
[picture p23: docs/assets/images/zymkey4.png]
zymkey4

#### [quickstart guide 🔗](https://docs.zymbit.com/getting-started/zymkey4/quickstart/){:target="_blank"}

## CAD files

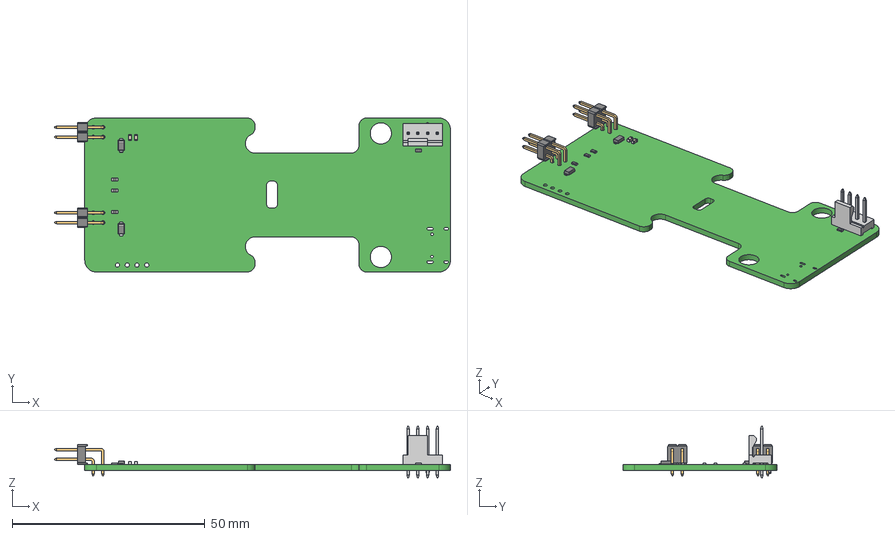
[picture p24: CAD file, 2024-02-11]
docs/assets/files/Fan_Unit_Dumb_V1.1.step
102.9 x 40.0 x 13.5 mm
res0603 x 4
6130xx21021_PIN x 4
6130xx21021_PIN_G x 4
User Library-SOD-123FL x 2
User Library-CAP_0603_CAP_0603_Lead_1 x 4
User Library-CAP_0603_CAP_0603_Body_1 x 2

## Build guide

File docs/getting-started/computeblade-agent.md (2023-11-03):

---
title: Setting up the ComputeBlade Agent
layout: page
parent: Getting Started
permalink: "/getting-started/computeblade-agent/"
nav_order: 3
---

The [computeblade-agent](https://github.com/Uptime-Lab/computeblade-agent) is an OS agent interfacing with the ComputeBlade hardware.
It controls fan speed, LEDs and handles common events e.g. to identify/find an individual blade in a server rack.
In addition, it exposes hardware- and agent-related metrics on a Prometheus endpoint.

Detailed configuration options and install instructions are documented on the [GitHub Repo](https://github.com/uptime-lab/computeblade-agent). The **TL;DR** in case you just want to install it:
```bash
curl -L -o /tmp/computeblade-agent-installer.sh https://raw.githubusercontent.com/Uptime-Lab/computeblade-agent/main/hack/autoinstall.sh
chmod +x /tmp/computeblade-agent-installer.sh
/tmp/computeblade-agent-installer.sh
```

Here's a small demo video of the identify operation in-action:
Video (https://youtu.be/ik-7X-YZQ9c)

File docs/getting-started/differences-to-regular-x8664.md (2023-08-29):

---
title: RasberryPi compared to regular x86/64 processors
layout: page
parent: Getting Started
permalink: "/getting-started/rpi-compare-x86/"
nav_order: 2
---

This page compares the RaspberryPi platform against regular commodity hardware (x86/64) and things to watch out for.

# x86/amd64 vs ARM64 architecture

The x86 platform, prevalent in regular computers, offers robust performance, broad software compatibility, and a variety of operating system options. It's well-suited for resource-intensive tasks, software development, and versatile computing needs.

In contrast, the ARM64 platform, exemplified by the RaspberryPi, prioritizes power efficiency, compact form factors, and IoT/embedded applications. With a strong Linux ecosystem, ARM64 devices are tailored for specialized projects, educational exploration, and scenarios where low power consumption and small size are paramount.

Ultimately, the choice between x86 and ARM64 depends on the intended purpose, ranging from high-performance computing to energy-efficient projects and hands-on learning experiences.

The software support for ARM64 is gaining significant improvements since 2022, when Apple switched its notebooks to the same architecture.

While not being as powerful compared to a regular Server, the RaspberryPi Compute Module can run demanding software while keeping power consumption low.
This allows high-density dedicated servers (aka the ComputeBlade) running without having a full datacenter in the basement.

# Compatibility
Given the difference in architecture, the RaspberryPi does not support all software out of the box.
However, no ARM64 support is the exception rather than the rule.

# Boot Process Differences: x86 vs. ARM64 (RaspberryPi)

The boot process of x86 and ARM64 platforms, such as the RaspberryPi, diverges due to architectural distinctions and hardware considerations:

### x86 Boot Process:
1. **Firmware:* x86 computers typically use BIOS (Basic Input/Output System) or UEFI (Unified Extensible Firmware Interface) as their firmware. These firmware interfaces initialize hardware components, locate the boot device, and load the bootloader.

2. **Bootloader:** The bootloader, often GRUB or similar software, loads the operating system kernel from the boot device (usually a hard drive or SSD). It also handles the selection of the desired operating system if multiple options are available.

3. **Kernel Initiation:** Once the bootloader hands off control to the operating system kernel, the kernel initializes the hardware, mounts the root filesystem, and starts the user-space processes.

### ARM64 Boot Process (RaspberryPi):
> More details can be found in the [official documentation](https://www.raspberrypi.com/documentation/computers/compute-module.html).

1. **Firmware:** The RaspberryPi uses a specialized bootloader known as the RaspberryPi Bootloader (often referred to as `bootcode.bin`). This firmware, stored in the boot partition of the SD card, initializes the ARM processor cores, memory, and peripherals.

2. **GPU Firmware:** The GPU firmware (included in `bootcode.bin`) initializes the VideoCore GPU and loads the initial kernel image (`kernel.img`) into memory.

3. **ARM64 Kernel:** The loaded kernel initializes the ARM64 processor cores, configures memory, and starts essential kernel processes. The kernel is typically paired with a device tree blob (`*.dtb` file) that describes the hardware configuration.

4. **Kernel Initiation:** Once the ARM64 kernel is operational, it mounts the root filesystem, initializes drivers, and launches user-space processes.

The ARM64 boot process for the RaspberryPi involves a multi-stage process that leverages the GPU firmware and a specialized bootloader, ultimately loading the ARM64 kernel and initializing the system. In contrast, x86 systems use more standardized firmware interfaces and bootloaders, similar to those found in traditional desktop and laptop computers.

These differences reflect the distinct hardware architectures of x86 and ARM64 platforms, influencing how the system initializes and loads the operating system.

## U-Boot, UEFI and more

Once working with more specific operating systems for the RaspberryPi, projects like [u-boot](http://u-boot.readthedocs.io) or [pftf/RPI4](https://github.com/pftf/RPi4) (UEFI for RaspberryPi 4) appear.

Without going into too much detail here, both are more standardised bootloaders with u-boot being very specific for embedded devices and UEFI being a more mainstream solution.
In the context of the RaspberryPi, both are loaded **instead** of the Linux kernel directly.

Once executed, they take care of further initialising the hardware and loading the actual Linux kernel.
E.g. [Talos Linux](http://talos.dev), a tailored distribution of Kubernetes, uses u-boot for all of its supported embedded boards where it acts as a standardisation layer of the boot process.

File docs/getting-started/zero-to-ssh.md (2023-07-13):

---
title: From Zero to SSH
layout: page
parent: Getting Started
permalink: "/getting-started/zero-to-ssh/"
nav_order: 1
---

This getting started guide is intended to provide a generic starting ground, covering all steps required to get an SSH session to your blade.
While you can use the Blade with an SD-Card or the embedded eMMC as boot drive, this guide focuses on using the NVMe drive.

# 0. Checklist

- [ ] A PoE capable switch (802.3af or 802.3at). [Here](/main-features/ethernet/) is a list of known-working models.
- [ ] A LAN cable
- [ ] Any version of the ComputeBlade (check [here](/) for details )
- [ ] A [Raspberry Pi Compute Module 4 (CM4)](https://www.raspberrypi.com/products/compute-module-4/?variant=raspberry-pi-cm4001000). In case you plan running [Kubernetes](http://kubernetes.io) on it, make sure to get at least 4GB of memory.
- [ ] An NVMe SSD. Any capacity works, ~500GB seems to be the sweet-spot as of July 2023. A list of already verified drives is located [here](/supported-ssds/).
- [ ] (recommended) A heatsink for the CM4
- [ ] An NVMe to USB adapter. The cheapest option supporting PCIe-based NVMe drives should work.

# 1. Setting up the hardware

1. Install the CM4 on the ComputeBlade
Make sure to line up the CM4 in the correct orientation. It fits only one way! Apply gentle downward facing pressure to the CM4 - you will hear the connectors snapping in.

2. Install the heatsink on the CM4.
Make sure there is sufficient heihgt clearance, when not using the heatsink offered by the ComputeBlade project

3. Plug everything into your PoE switch
This is just a sanity check to see if everything was installed properly!
The LEDs should power on. If they do not, something is not installed correctly or your switch might be incompatible.

4. Unplug the ComputeBlade again
As stated in (3), this was just a sanity check.

# 2. Setting up the OperatingSystem on the NVMe SSD

{: .note }
Depending on when you bought your CM4, you might have to upgrade the firmware first. Check [here]() for more details!

## 2.1. Choose an Operating System
> Make sure to choose the 64bit versions!

There are several supported OSes supported by the RaspberryPi, **but** not all are able to boot from the NVMe SSD out of the box.
We recommend you to choose one of the followings:
- [Ubuntu 22.04 LTS](https://ubuntu.com/download/raspberry-pi/thank-you?version=24.04&architecture=server-arm64+raspi) (NVME support starting with 22.04.2)
- [Ubuntu 23.04](https://ubuntu.com/download/raspberry-pi/thank-you?version=23.04&architecture=server-arm64+raspi) (NVME support starting with 22.04.2) (The Linux Kernel 6.2 shows some performance improvements for some NVMe drives)
- [Raspberry Pi OS Lite](https://www.raspberrypi.com/software/)

## 2.2. Flash the Operating System on the NVMe drive

### 2.2.1 Install the NVMe drive in the USB-to-NVMe adapter

Make sure the drive is placed in the connector and does not disconnect when you plug it into your computer.
In case your adapter comes with an enclosure, you don't have to install it, as you'll remove the drive very soon again.

### 2.2.2 Use the official RaspberryPi Imager to flash your OS
> As stated in 2.1., make sure to choose the 64 bit version.

1. Install the latest version of the [Raspberry Pi Imager](https://www.raspberrypi.com/software/)
2. Choose your desired OS. The 64bit lite version of Raspberry Pi OS is located in the *Raspberry Pi OS (other)* section. Ubuntu can be found in *Other general-purpose OS*.
3. Click the settings icon on the bottom right and configure the hostname (e.g. `blade0`), Enabel SSH and set username and password. As a security best-practice, it's recommended to enforce public-key authentication. In case this is new for you, use the password authentication - you'll get to it while playing around with Linux!
4. Choose the storage. Your NVMe drive should show up here! If it does not, something went wrong. Check if it is plugged in your computer and the NVMe drive is installed correctly on it.

# 3. Finalizing your Blade
1. Remove the NvMe drive from the adapter
2. Install it on the Blade
3. Connect the Blade to your PoE switch
4. Wait a few minutes for it to boot. Give it some time! The first boot expands the root file system to accomodate your SSD capacity
5. Connect to your blade via SSH. You can check the DHCP leases in your router for the hostname configured in (2.2.2) or rely on mDNS (works for Ubuntu 23.04 only): `ssh <username>@<hostname>.local`, e.g. `ssh xvzf@blade0.local`
6. *COMING SOON*: Install the ComputeBlade Agent to auto-configure LEDs and the [FAN-Unit](/main-features/fan-unit-connector/)

# 4. Next Steps

**Do whatever you want!**

Here are some inspirations:
- Build a Kubernetes homelab for testing
- Power your smarthome using [HomeAssistant](https://www.home-assistant.io) on your blade.
- Run your own CICD workloads on it, e.g. by hosting your own [Github Actions Runner](https://docs.github.com/en/actions/hosting-your-own-runners)
- Run your own backup-server Blade with Timemachine (e.g. using [this](https://hub.docker.com/r/mbentley/timemachine) docker image)
- Host a custom Discord-Bot, just like the [one powering the UptimeLab Discord](https://github.com/Uptime-Lab/Uptime-Bot).

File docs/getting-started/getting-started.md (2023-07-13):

---
title: Getting Started
layout: page
permalink: "/getting-started/"
has_children: true
nav_order: 2
---

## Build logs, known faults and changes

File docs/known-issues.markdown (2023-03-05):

---
title: Known Issues
layout: page
permalink: "/known-issues/"
nav_order: 6
---
## Known Issues

---
PoE negotiation issue with NetGear switches:\
**GS324TP v1\
QS110TPP v1**

There is a problem with PoE mode negotiation when using FTP twisted pair. I recommend using UTP in this case.
But maybe this is just my problem. No one else has been able to reproduce it yet.

---

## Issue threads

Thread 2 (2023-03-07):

PoE / PoE+ Specs possibly out of scope...

hdell, 2023-03-07:
- PoE+ and use 25.5W as the MAX as per IEEE 802.3at-2009 spec; 30W is surge power for a very short period of time.
- Also, regular PoE is 12.95W MAX as per IEEE 802.3af-2003 spec; 15W is surge power for a very short period of time.

Her are the two open references that I found that describe POE:
1. https://en.wikipedia.org/wiki/Power_over_Ethernet
2. https://www.inscapedata.com/pdf/IEEE802.3at_Standard.pdf

Thus far I found two place that need updating for POE:
1. docs.computeblade.com/about/ and
2. docs.computeblade.com/main-features/ethernet/.
(Plus please remove the extra backslash; also can you include a reference the PN # of the PoE module so one can look up the specs. Using AG5400 Series?)

Finally, I would add some comments that PoE Network Switches not always provide full MAX W (25.5W x N Ports). For example, a 16 Port Netgear only can provide 76W for PoE+ without adding an additional PSU plus Netgear has different models with different MAX W. There has been some discussion on in the Discord on this topic. For example:

https://www.amazon.com/NETGEAR-16-Port-Gigabit-Ethernet-Unmanaged/dp/B01HUOE12G @ 76W vs
https://www.amazon.com/NETGEAR-16-Port-Gigabit-Ethernet-Unmanaged/dp/B07DNT7JCT @ 183W vs
https://www.amazon.com/NETGEAR-16-Port-Gigabit-Ethernet-Unmanaged/dp/B08CQ8HVD3 @ 260W

Also, folks wanted to know how much the cost of power would be running blades 24/7. I calculated a 100W budget for 10 Blades; cost should not be more than $1 USD per Day (rounded up for cost variance) using average kWh energy usage fee in USA to get a base line understanding. That is equal to skipping 3 Cups of Coffee at Starbucks (average cost per Cup of $3.15 USD) to save enough monies to cover the power usage for the week. Some Folks are on a tight budget, and I wanted to relate this to something a person could easily understand and choose to skip to pay for the cost of power for the Blades.

hdell, 2023-03-07:
I just found some of the details everyone has been asking about on Discord; in the FAQ under "How much does it cost in electricity?" and "Power Consumption and the choice of the switch".

pxpunx, 2023-03-13:
I pushed the linked PR, then saw this issue. Most of what you've raised here was covered by my original commit, but I added a few additional corrections and some more information based on your suggestions.

hdell, 2023-03-13:
I am sorry I don't understand any of this... Are you saying you have made changes?

I am noob with al these things like "liked PR", Discord, Git and such. The docs give the impression that one can continuously draw "up to 30W" which IMHO is incorrect based upon all of the IEEE specs and other research materials that that I provided here and on Discord https://discordapp.com/channels/952334175501946902/1082921571183771658. Can you 1) please describe how to find your comments that you mention or can import or provide a URL to this content here for completeness; and 2) what is the MAX W that we are agreeing upon? What is the PoE SIL that the Blade uses so we can be more specific?

Closed 2023-03-19.

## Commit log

2023-03-05 The spice must flow
    documentation appear
2023-03-13 updated PoE+ power
2023-03-13 added power cost information
2023-03-19 AG5405 confirmed
    added webrick to Gemfile.
    AG5405 confirmed.
    added switches
2023-07-01 docs: Add additional SSDs and validated switches
2023-09-22 Update stealth-mode.md
    Added how to switch off LEDs on the Ethernet port
2024-02-11 Added 3d models for Compute Blade v1 and Fan Unit
    as well as minor changes
    [Fan_Unit_Dumb_V1.1.step]
2024-04-26 Update fan-unit-connector.md
    added how to find UART5

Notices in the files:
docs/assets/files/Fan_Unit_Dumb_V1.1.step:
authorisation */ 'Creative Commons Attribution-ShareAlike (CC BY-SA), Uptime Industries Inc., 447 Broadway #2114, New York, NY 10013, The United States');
